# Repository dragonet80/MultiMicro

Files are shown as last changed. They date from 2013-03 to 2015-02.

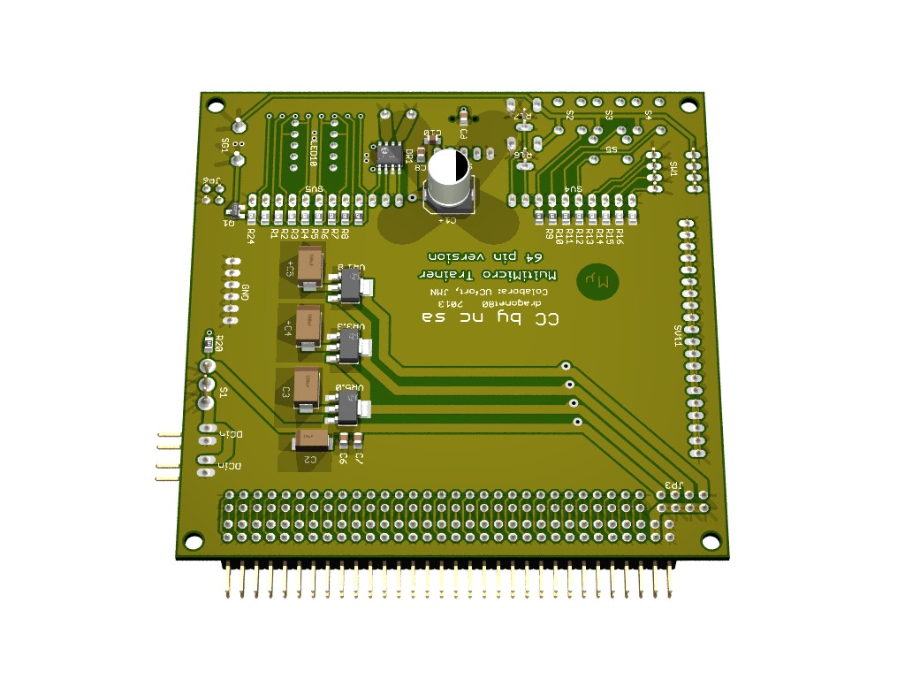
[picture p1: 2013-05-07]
Base/multiMicro_base_64pin_BOTTOM.jpg

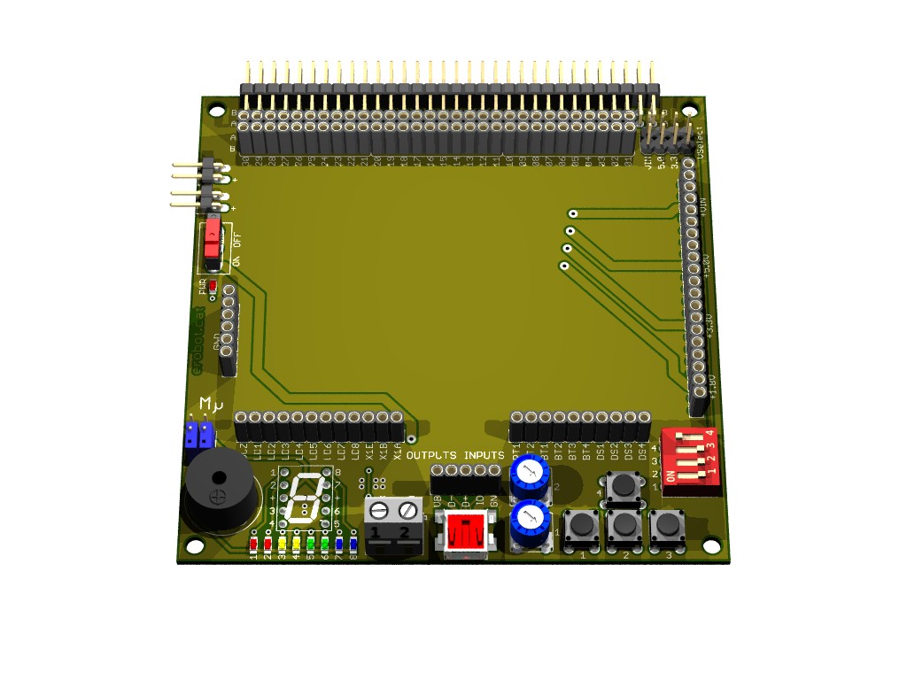
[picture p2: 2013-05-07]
Base/multiMicro_base_64pin_TOP.jpg

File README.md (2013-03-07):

MultiMicro
==========

MultiMicro Trainer is an small, simple and affordable microcontroller trainer everyone can use.
Its size is 10x10 cm, so you can order at a cheap price on online pcb manufarurers.

It's intended to be universal with any microcontroller from 6 to 100 pins and 5, 3.3 and 1.8 V.

It is formed by three parts:
* Base Trainer. It is the main pcb. It has voltage regulators, space for small breadboard, 8 push-buttons, 8 leds, 2 potenciometers and a buzzer. Plus, all connectors and pinheaders.
* Microcontroller adapter. You can make any adapter for your favorite microcontroller. You plug it to Base Trainer thru a 3x30 pinhead connector.
* Add-on boards. To add functionality. Preferred size is in multiples of 5x5 cm, to better fit Base Trainer, but can be any size.

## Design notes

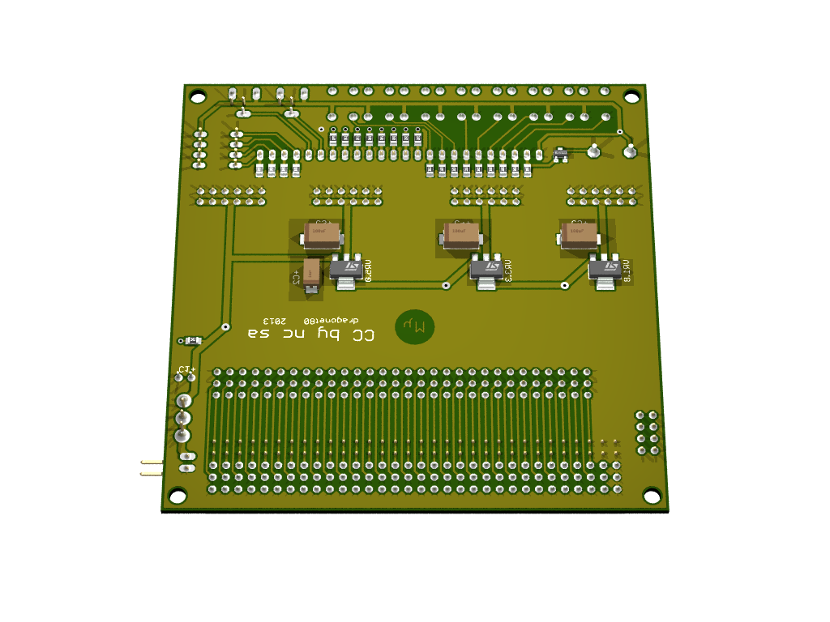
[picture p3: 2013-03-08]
Base/ARE_entrenadora_modular_doblecara_bis_BOT.bmp

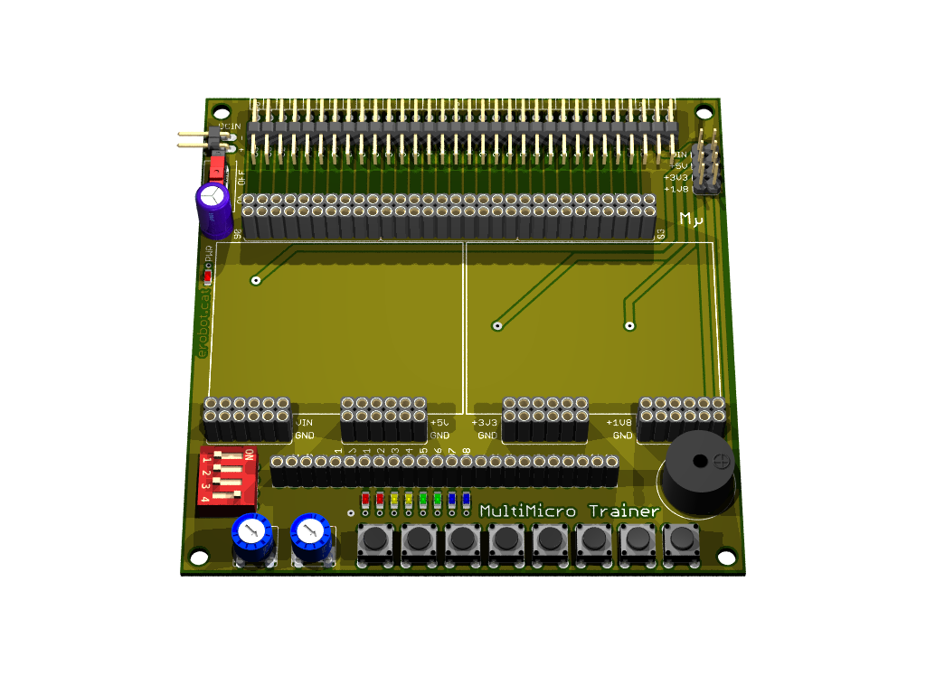
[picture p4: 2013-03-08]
Base/ARE_entrenadora_modular_doblecara_bis_TOP.bmp

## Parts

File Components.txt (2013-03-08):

* BASE:
-> 10uF Tantalo C: http://www.ebay.es/itm/10uF-TANTALUM-CAPACITOR-CASE-SIZE-C-10PCS-LOT-/251163093236#ht_500wt_1054
-> 100uF Tantalo E: http://www.ebay.es/itm/250974323237?ssPageName=STRK:MEWNX:IT&_trksid=p3984.m1439.l2649#ht_500wt_1054
-> 1.8V regulador: http://www.ebay.es/itm/200682889242?ssPageName=STRK:MEWNX:IT&_trksid=p3984.m1439.l2649
-> 3.3V regulador: http://www.ebay.es/itm/260700726343?ssPageName=STRK:MEWNX:IT&_trksid=p3984.m1439.l2649
-> 5.0V regulador: http://www.ebay.es/itm/130750914480?ssPageName=STRK:MEWNX:IT&_trksid=p3984.m1439.l2649
-> Leds de colors: http://www.ebay.es/itm/360537732340?ssPageName=STRK:MEWNX:IT&_trksid=p3984.m1439.l2649
-> 3x40 pinhead 90º: http://www.ebay.es/itm/180962786708?ssPageName=STRK:MEWNX:IT&_trksid=p3984.m1439.l2649
-> 3x40 pinhead femella: http://www.ebay.es/itm/170881419323?ssPageName=STRK:MEWNX:IT&_trksid=p3984.m1439.l2649
-> 2x40 pinhead femella: http://www.ebay.es/itm/170590329710?ssPageName=STRK:MEWNX:IT&_trksid=p3984.m1439.l2649
-> 1x40 pinhead femella: http://www.ebay.es/itm/170621688248?ssPageName=STRK:MEWNX:IT&_trksid=p3984.m1439.l2649
-> 2x40 pinhead: http://www.ebay.es/itm/170578500842?ssPageName=STRK:MEWAX:IT&_trksid=p3984.m1438.l2649
-> Mini breadboard + cables: http://www.ebay.es/itm/310513842038?ssPageName=STRK:MEWAX:IT&_trksid=p3984.m1438.l2649
-> Buzzer: http://www.ebay.es/itm/290576011848?ssPageName=STRK:MEWAX:IT&_trksid=p3984.m1438.l2649

* ADAPTADORES:
-> 1x40 pinhead femella 90º: http://www.ebay.es/itm/170876801011?ssPageName=STRK:MEWNX:IT&_trksid=p3984.m1439.l2649
-> 2x40 pinhead femella 90º: http://www.ebay.es/itm/160939073658?ssPageName=STRK:MEWNX:IT&_trksid=p3984.m1439.l2649
-> 2x20 pinhead femella 90º: http://www.ebay.es/itm/121021379218?ssPageName=STRK:MEWNX:IT&_trksid=p3984.m1439.l2649
-> 10uF Ceràmic 0805: http://www.ebay.es/itm/220983887703?ssPageName=STRK:MEWNX:IT&_trksid=p3984.m1439.l2649

* MÒDULS:

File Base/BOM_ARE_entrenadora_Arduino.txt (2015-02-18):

* ATMega32u4 tqfp:
http://www.ebay.es/itm/291281726764

* Breadboard + cables:
http://www.ebay.es/itm/310513842038

* Interruptor:
http://www.ebay.es/itm/310569872090

* Adaptador de voltatge:
http://es.farnell.com/texas-instruments/txs0104ed/ic-volt-level-translator-4bit/dp/1607892
http://www.ti.com/product/txs0104e/samplebuy
http://www.ebay.es/itm/TEXAS-INSTRUMENTS-TXS0104ED-IC-SM-LOGIC-TRANSLATOR-/351067941092

* Display 0,96" SPI:
http://www.ebay.es/itm/170842974902

* Potenciòmetres:
http://www.ebay.es/itm/321635537380

* Diodes:
http://www.ebay.es/itm/400647265186

* Ferrites:
http://www.ebay.es/itm/191479162526

* Mosfets tipus N:
http://www.ebay.es/itm/181291847700

* Mosfets tipus P:
http://www.ebay.es/itm/261261782429

* Condensadors 100uF 16V tipus C:
http://www.ebay.es/itm/291190614250

* 2x40 Male Pin Header 90º:
http://www.ebay.es/itm/140850530831

* Botons through hole:
http://www.ebay.es/itm/251146519833

* ESP8266 01:
http://www.ebay.es/itm/131334864936

* NRF24L01+:
http://www.ebay.es/itm/1pcs-NRF24L01-2-4GHz-Antenna-Wireless-Transceiver-Module-For-Microcontr-/171462149587

* HC-06:
http://www.ebay.es/itm/HC-06-RS232-Wireless-Serial-4-Pin-Bluetooth-RF-Transceiver-Module-With-backplane-/130984479388

* HM-10:
http://www.ebay.es/itm/HM-10-Transparent-Bluetooth-4-0-Serial-Port-Module-with-Logic-Level-Translator-/201260428325

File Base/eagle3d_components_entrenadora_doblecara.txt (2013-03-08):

INTERRUPTOR DIP(S1): SWITCH_SECME_1K2_SLB
BUZZER (SG1): SPC_BUZZER_TDB
PULSADOR (S2..S9): SWITCH_B3F_10XX1
POTENCIOMETRE (R22..R23): RES_DIS_TRIM_T7_YB

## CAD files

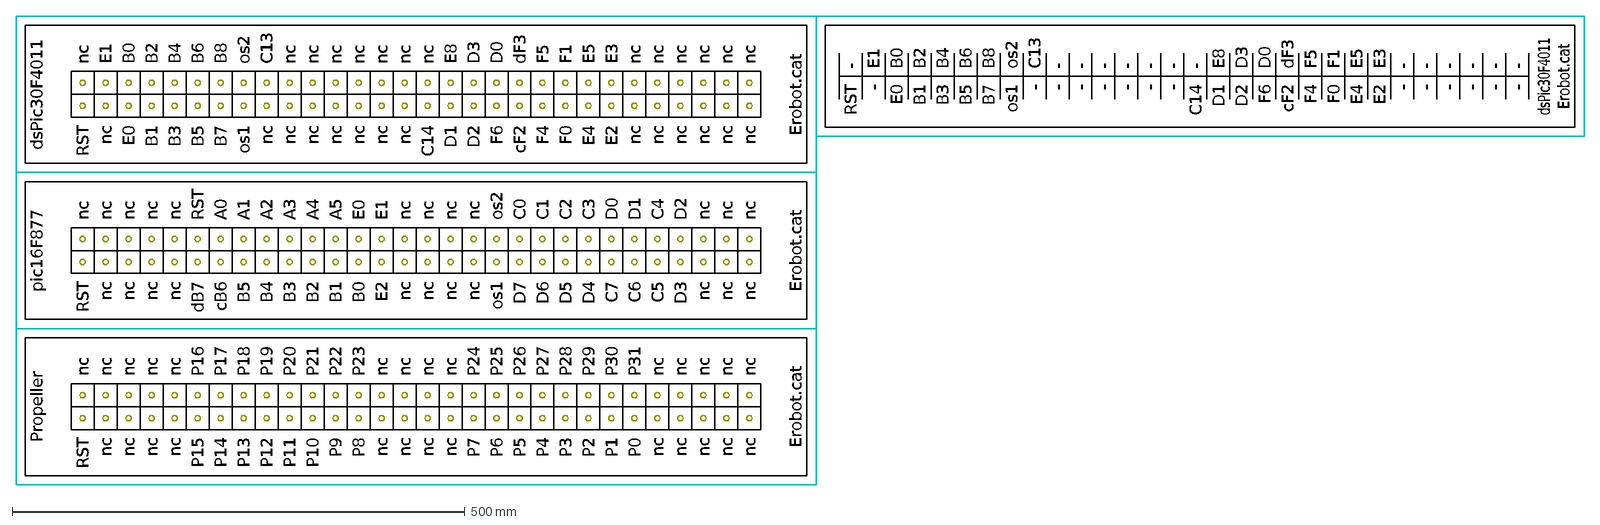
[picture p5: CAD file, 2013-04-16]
Plantilla_pins_entrenadora.dxf
RST
nc
E0
B1
B3
B5
B7
os1
C14
D1
D2
F6
cF2
F4
F0
E4
E2
E3
E5
F1
F5
dF3
D0
D3
E8
C13
os2
B8
B6
B4
B2
B0
E1
dsPic30F4011
Erobot.cat
dB7
cB6
D7
D6
D5
D4
C7
C6
C5
C4
C3
C2
C1
C0
A5
A4
A3
A2
A1
A0
pic16F877
P15
P14
P13
P12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

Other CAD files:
Plantilla_pins_entrenadora.dwg

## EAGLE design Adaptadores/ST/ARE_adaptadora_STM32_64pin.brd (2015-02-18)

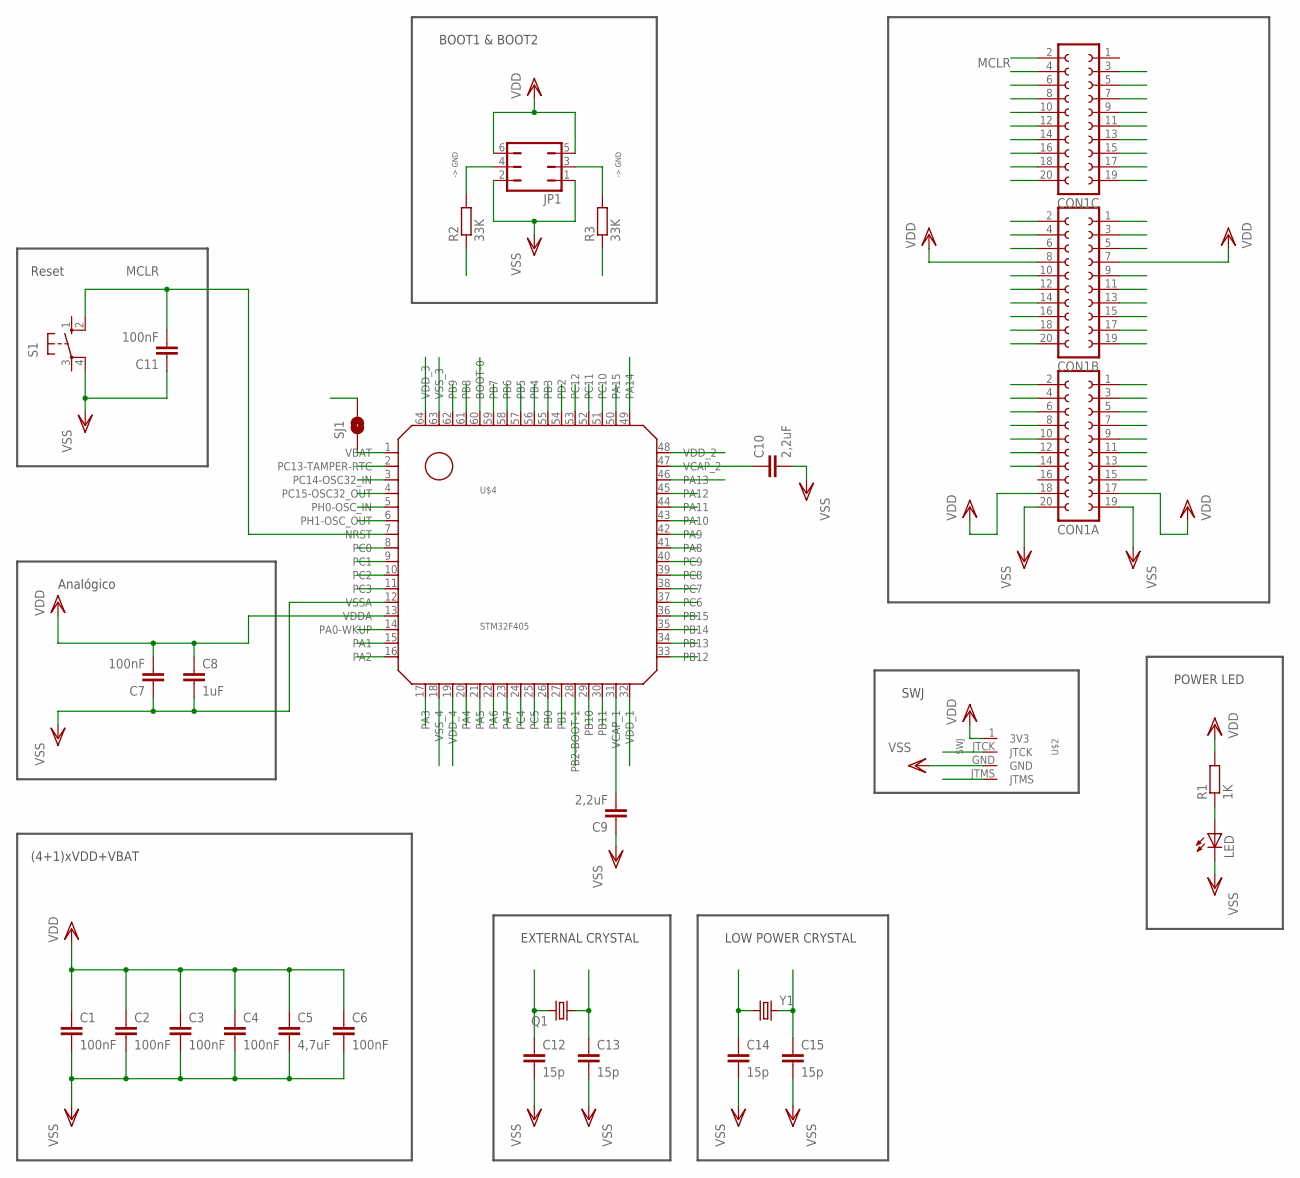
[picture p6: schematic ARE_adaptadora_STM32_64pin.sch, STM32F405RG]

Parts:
C1, C2, C3, C4, C6, C7, C11: 100nF; C0805K
C5: 4,7uF; C0805K
C8: 1uF; C0805K
C9, C10: 2,2uF; C0805K
C12, C13, C14, C15: 15p; C0805
CON1A, CON1B, CON1C: FE10-2W
JP1: JP3Q
LED: LEDCHIPLED_0805; CHIPLED_0805
Q1: CRYSTALHC18U-V; HC18U-V
R1: 1K; R0805
R2, R3: 33K; R0805
S1: 10-XX; B3F-10XX; MPN B3F-1000
SJ1: SOLDERJUMPERNO; SJ_2S-NO
U$2: SWJ
U$4: STM32F405; LQFP64
Y1: CRYSTAL32-SMD; CRYSTAL-32KHZ-SMD

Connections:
BOOT0: R2.1, U$4.60 (BOOT-0)
BOOT1: CON1B.3, R3.1, U$4.28 (PB2-BOOT-1)
JTCK: CON1A.3, U$2.JTCK, U$4.49 (PA14)
JTMS: CON1A.2, U$2.JTMS, U$4.46 (PA13)
MCLR: C11.2, CON1C.2, S1.2 (S1), U$4.7 (NRST)
unnamed: C10.1, U$4.47 (VCAP_2)
unnamed: C9.2, U$4.31 (VCAP_1)
unnamed: CON1C.4, U$4.2 (PC13-TAMPER-RTC)
unnamed: LED.A, R1.1
unnamed: CON1C.7, U$4.8 (PC0)
unnamed: CON1C.10, U$4.9 (PC1)
unnamed: CON1C.9, U$4.10 (PC2)
unnamed: CON1C.12, U$4.11 (PC3)
unnamed: CON1C.11, U$4.14 (PA0-WKUP)
unnamed: CON1C.14, U$4.15 (PA1)
unnamed: CON1C.13, U$4.16 (PA2)
unnamed: CON1C.16, U$4.17 (PA3)
unnamed: CON1C.15, U$4.20 (PA4)
unnamed: CON1C.18, U$4.21 (PA5)
unnamed: CON1C.17, U$4.22 (PA6)
unnamed: CON1C.20, U$4.23 (PA7)
unnamed: CON1C.19, U$4.24 (PC4)
unnamed: CON1B.2, U$4.25 (PC5)
unnamed: CON1B.1, U$4.26 (PB0)
unnamed: CON1B.4, U$4.27 (PB1)
unnamed: CON1B.6, U$4.29 (PB10)
unnamed: CON1B.5, U$4.30 (PB11)
unnamed: CON1B.9, U$4.33 (PB12)
unnamed: CON1B.10, U$4.34 (PB13)
unnamed: CON1B.11, U$4.35 (PB14)
unnamed: CON1B.12, U$4.36 (PB15)
unnamed: CON1B.13, U$4.37 (PC6)
unnamed: CON1B.14, U$4.38 (PC7)
unnamed: CON1B.15, U$4.39 (PC8)
unnamed: CON1B.16, U$4.40 (PC9)
unnamed: CON1B.17, U$4.41 (PA8)
unnamed: CON1B.18, U$4.42 (PA9)
unnamed: CON1B.19, U$4.43 (PA10)
unnamed: CON1B.20, U$4.44 (PA11)
unnamed: CON1A.1, U$4.45 (PA12)
unnamed: CON1A.4, U$4.50 (PA15)
unnamed: CON1A.5, U$4.51 (PC10)
unnamed: CON1A.6, U$4.52 (PC11)
unnamed: CON1A.7, U$4.53 (PC12)
unnamed: CON1A.8, U$4.54 (PD2)
unnamed: CON1A.9, U$4.55 (PB3)
unnamed: CON1A.10, U$4.56 (PB4)
unnamed: CON1A.11, U$4.57 (PB5)
unnamed: CON1A.12, U$4.58 (PB6)
unnamed: CON1A.13, U$4.59 (PB7)
unnamed: CON1A.14, U$4.61 (PB8)
unnamed: CON1A.15, U$4.62 (PB9)
unnamed: JP1.4, R2.2
unnamed: JP1.3, R3.2
P12OSC0: C13.1, CON1C.5, Q1.1, U$4.5 (PH0-OSC_IN)
P12OSC1: C12.1, CON1C.8, Q1.2, U$4.6 (PH1-OSC_OUT)
P12OSC320: C14.1, CON1C.3, U$4.3 (PC14-OSC32_IN), Y1.X1 (1)
P12OSC321: C15.1, CON1C.6, U$4.4 (PC15-OSC32_OUT), Y1.X2 (2)
VBAT: SJ1.1, U$4.1 (VBAT)
VDD: C1.1, C2.1, C3.1, C4.1, C5.1, C6.1, C7.2, C8.1, CON1A.17, CON1A.18, CON1B.7, CON1B.8, JP1.5, JP1.6, R1.2, SJ1.2, U$2.1 (3V3), U$4.13 (VDDA), U$4.19 (VDD_4), U$4.32 (VDD_1), U$4.48 (VDD_2), U$4.64 (VDD_3)
VSS: C1.2, C2.2, C3.2, C4.2, C5.2, C6.2, C7.1, C8.2, C9.1, C10.2, C11.1, C12.2, C13.2, C14.2, C15.2, CON1A.19, CON1A.20, JP1.1, JP1.2, LED.C, S1.4 (P1), U$2.GND, U$4.12 (VSSA), U$4.18 (VSS_4), U$4.63 (VSS_3)

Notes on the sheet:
(4+1)xVDD+VBAT
Reset
-> GND
BOOT1 & BOOT2
SWJ
Analógico
EXTERNAL CRYSTAL
POWER LED
LOW POWER CRYSTAL

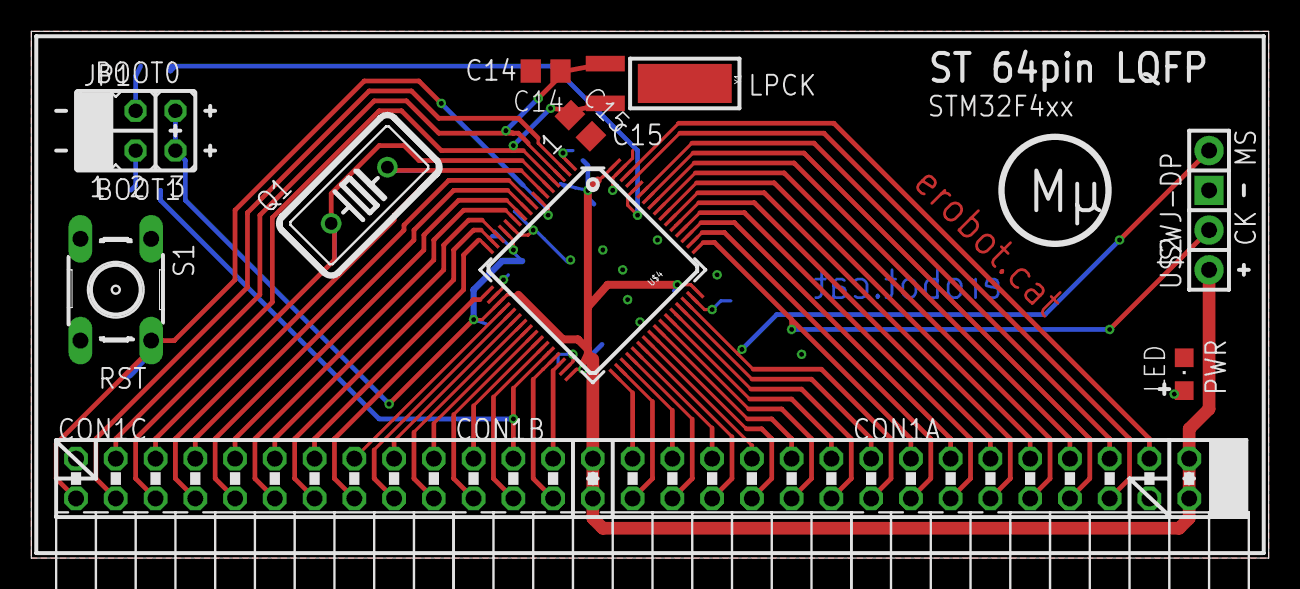
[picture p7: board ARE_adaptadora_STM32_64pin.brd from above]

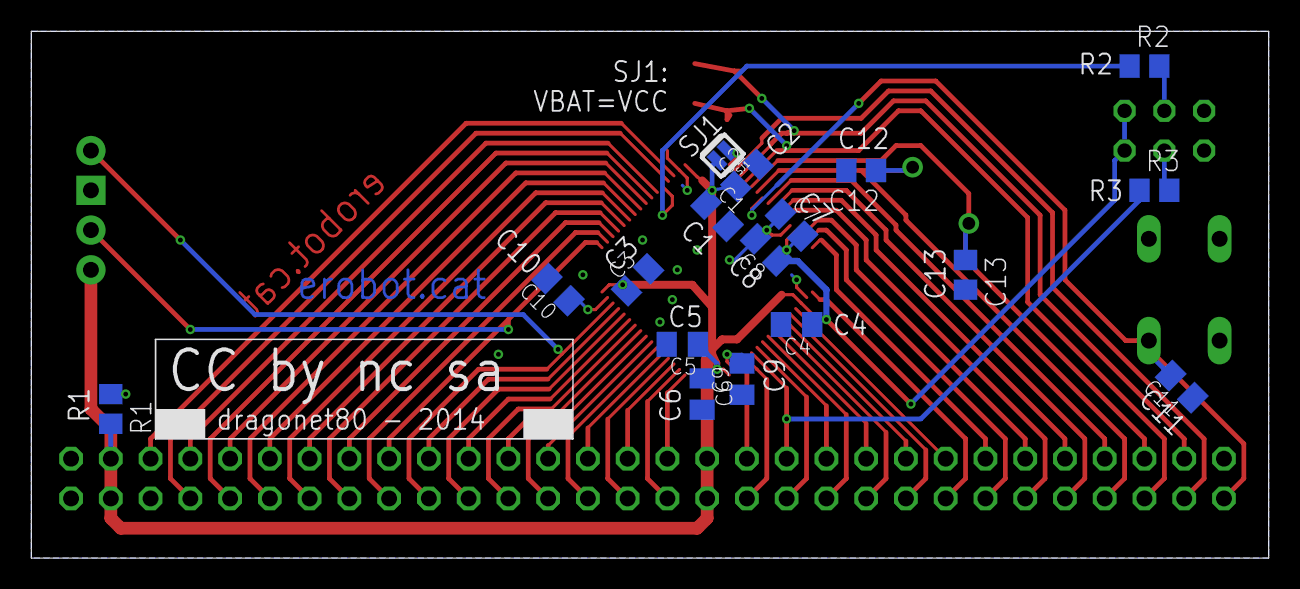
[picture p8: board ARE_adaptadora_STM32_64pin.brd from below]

Board: 2 copper layers, 79.1 x 33.7 mm, 29 parts (17 on the bottom side), 61 nets.

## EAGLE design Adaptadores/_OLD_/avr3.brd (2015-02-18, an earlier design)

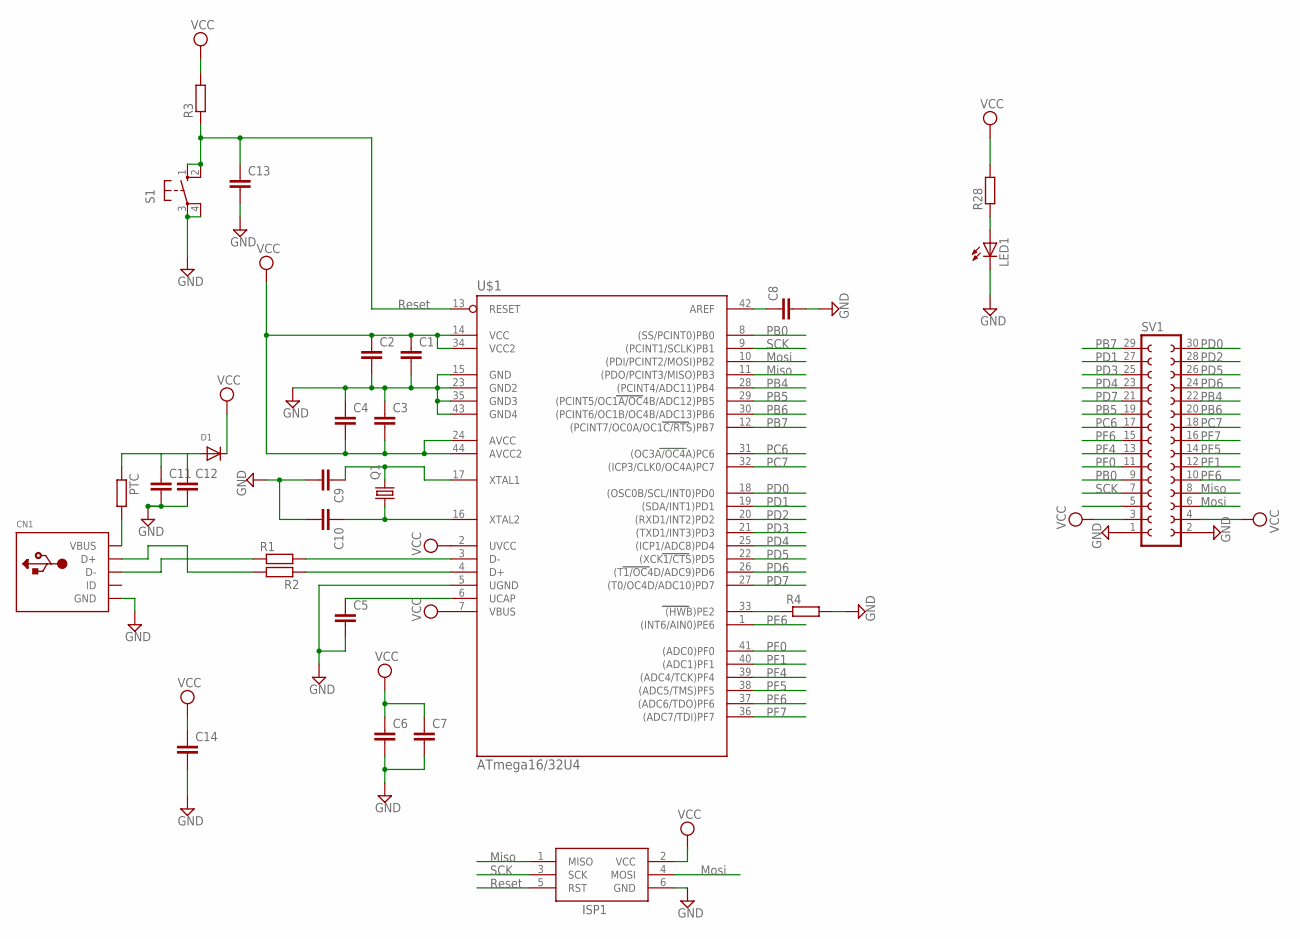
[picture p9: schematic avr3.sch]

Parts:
C1, C2, C3, C4, C5, C6, C7, C8, C9, C10, C11, C12, C13, C14: C-EUC1206; C1206
CN1: USBMINIB; USB-MINIB
D1: DIODESOD-123; SOD-123
ISP1: AVRISP-6; AVRISP
LED1: LEDCHIPLED_1206; CHIPLED_1206
PTC: R-EU_R1206; R1206
Q1: CRYSTALHC49UP; HC49UP
R1, R2, R3, R4, R28: R-EU_R1206; R1206
S1: 10-XX; B3F-10XX
SV1: FE15-2
U$1: ATmega16/32U4; TQFP44

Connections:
GND: C1.2, C2.2, C3.1, C4.1, C5.2, C6.2, C7.2, C8.2, C9.2, C10.2, C11.2, C12.2, C13.2, C14.2, CN1.GND, ISP1.6 (GND), LED1.C, R4.2, S1.3, S1.4 (P1), SV1.1, SV1.2, U$1.5 (UGND), U$1.15 (GND), U$1.23 (GND2), U$1.35 (GND3), U$1.43 (GND4)
MISO: ISP1.1 (MISO), SV1.8, U$1.11 ((PDO/PCINT3/MISO)PB3)
MOSI: ISP1.4 (MOSI), SV1.6, U$1.10 ((PDI/PCINT2/MOSI)PB2)
unnamed: C9.1, Q1.2, U$1.17 (XTAL1)
unnamed: C10.1, Q1.1, U$1.16 (XTAL2)
unnamed: C5.1, U$1.6 (UCAP)
unnamed: R4.1, U$1.33 ((HWB)PE2)
unnamed: R2.1, U$1.4 (D+)
unnamed: R1.2, U$1.3 (D-)
unnamed: CN1.D+, R2.2
unnamed: CN1.D-, R1.1
unnamed: CN1.VBUS, PTC.2
unnamed: C11.1, C12.1, D1.A, PTC.1
unnamed: C8.1, U$1.42 (AREF)
unnamed: LED1.A, R28.1
PB0: SV1.9, U$1.8 ((SS/PCINT0)PB0)
PB4: SV1.22, U$1.28 ((PCINT4/ADC11)PB4)
PB5: SV1.19, U$1.29 ((PCINT5/OC1A/OC4B/ADC12)PB5)
PB6: SV1.20, U$1.30 ((PCINT6/OC1B/OC4B/ADC13)PB6)
PB7: SV1.29, U$1.12 ((PCINT7/OC0A/OC1C/RTS)PB7)
PC6: SV1.17, U$1.31 ((OC3A/OC4A)PC6)
PC7: SV1.18, U$1.32 ((ICP3/CLK0/OC4A)PC7)
PD0: SV1.30, U$1.18 ((OSC0B/SCL/INT0)PD0)
PD1: SV1.27, U$1.19 ((SDA/INT1)PD1)
PD2: SV1.28, U$1.20 ((RXD1/INT2)PD2)
PD3: SV1.25, U$1.21 ((TXD1/INT3)PD3)
PD4: SV1.23, U$1.25 ((ICP1/ADC8)PD4)
PD5: SV1.26, U$1.22 ((XCK1/CTS)PD5)
PD6: SV1.24, U$1.26 ((T1/OC4D/ADC9)PD6)
PD7: SV1.21, U$1.27 ((T0/OC4D/ADC10)PD7)
PE6: SV1.10, U$1.1 ((INT6/AIN0)PE6)
PF0: SV1.11, U$1.41 ((ADC0)PF0)
PF1: SV1.12, U$1.40 ((ADC1)PF1)
PF4: SV1.13, U$1.39 ((ADC4/TCK)PF4)
PF5: SV1.14, U$1.38 ((ADC5/TMS)PF5)
PF6: SV1.15, U$1.37 ((ADC6/TDO)PF6)
PF7: SV1.16, U$1.36 ((ADC7/TDI)PF7)
RESET: C13.1, ISP1.5 (RST), R3.1, S1.1 (S), S1.2 (S1), U$1.13 (RESET)
SCK: ISP1.3 (SCK), SV1.7, U$1.9 ((PCINT1/SCLK)PB1)
VCC: C1.1, C2.1, C3.2, C4.2, C6.1, C7.1, C14.1, D1.C, ISP1.2 (VCC), R3.2, R28.2, SV1.3, SV1.4, U$1.2 (UVCC), U$1.7 (VBUS), U$1.14 (VCC), U$1.24 (AVCC), U$1.34 (VCC2), U$1.44 (AVCC2)

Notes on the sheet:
Reset
Miso
Mosi
SCK
PB7
PB6
PB5
PB4
PB0
PC6
PC7
PD0
PD1
PD2
PD3
PD4
PD5
PD6
PD7
PE6
PF0
PF1
PF4
PF5
PF6
PF7

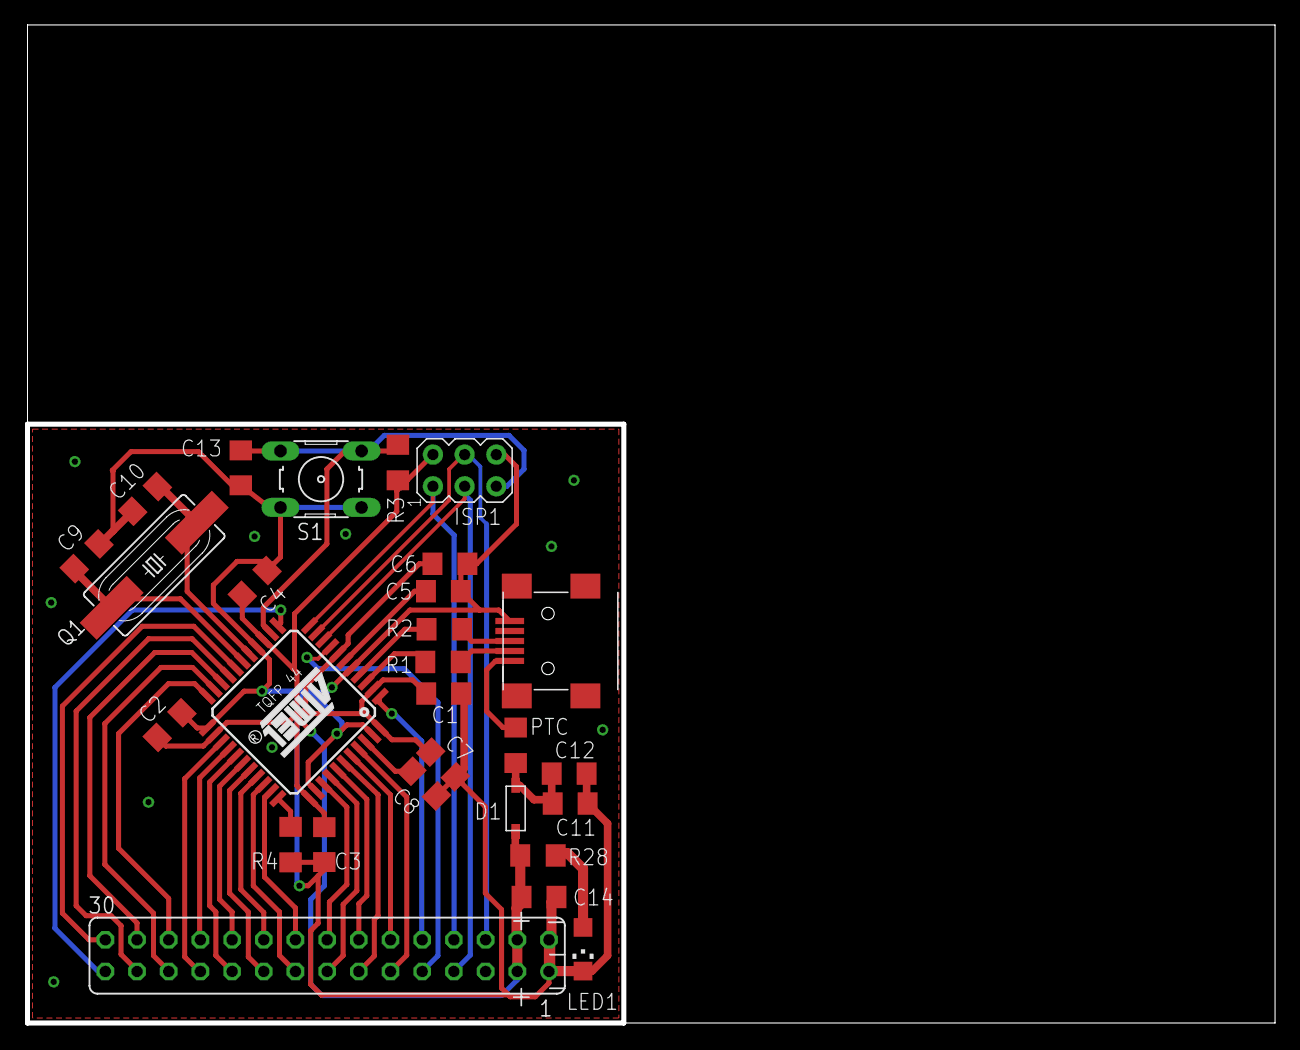
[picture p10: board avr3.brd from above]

Board: 2 copper layers, 100.0 x 80.0 mm, 28 parts (0 on the bottom side), 40 nets.

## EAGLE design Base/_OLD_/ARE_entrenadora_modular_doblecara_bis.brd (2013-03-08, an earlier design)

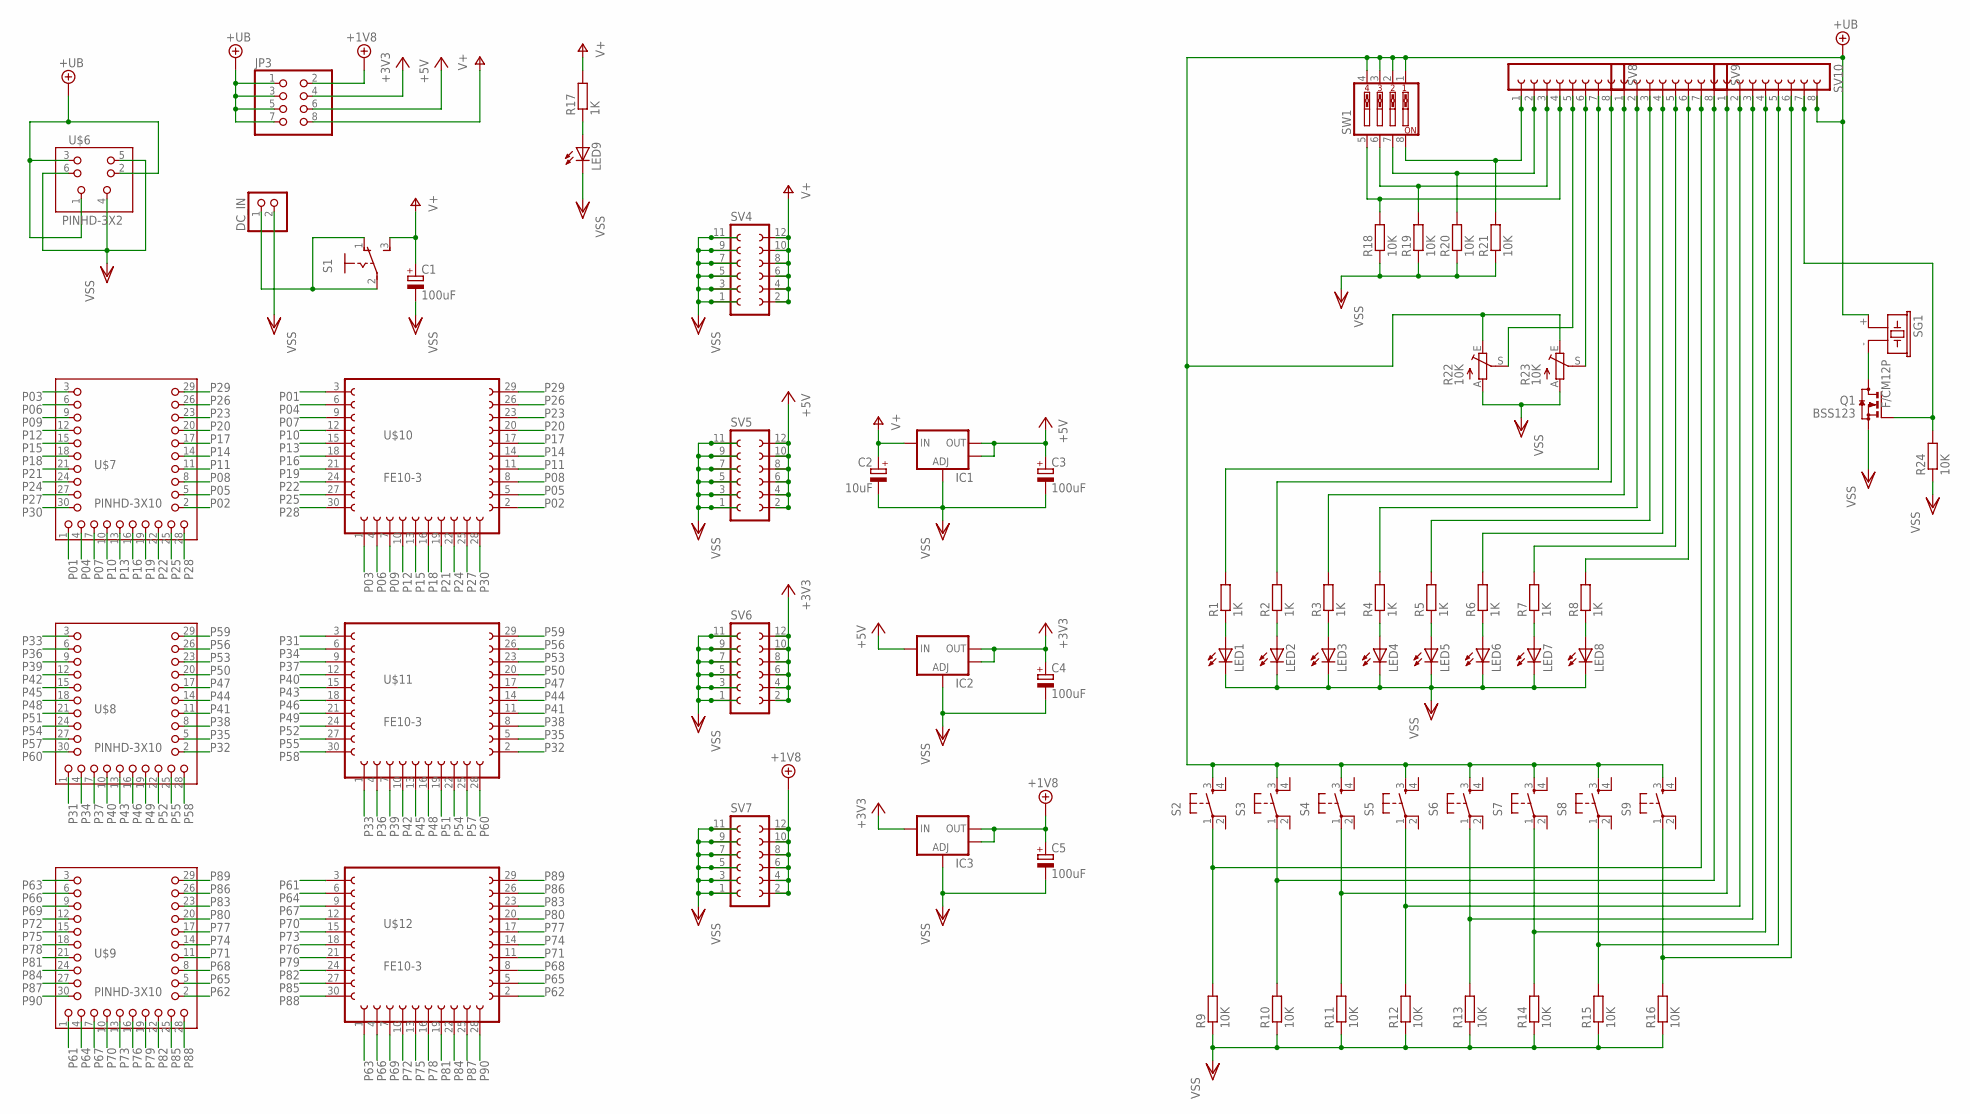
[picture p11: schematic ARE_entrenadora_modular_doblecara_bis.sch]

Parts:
C1: 100uF; E2,5-6
C2: 10uF; SMC_C
C3, C4, C5: 100uF; CT7343
DC_IN: PINHD-1X2/90; 1X02/90
IC1, IC2, IC3: V_REG_LM1117SOT223; SOT223
JP3: PINHD-2X4; 2X04
LED1, LED2, LED3, LED4, LED5, LED6, LED7, LED8, LED9: LEDCHIP-LED0805; CHIP-LED0805
Q1: BSS123; SOT23
R1, R2, R3, R4, R5, R6, R7, R8, R17: 1K; R0805
R9, R10, R11, R12, R13, R14, R15, R16, R18, R19, R20, R21, R24: 10K; R0805
R22, R23: 10K; CA6V
S1: 255SB
S2, S3, S4, S5, S6, S7, S8, S9: TAC_SWITCHPTH; TACTILE-PTH
SG1: F/CM12P
SV4, SV5, SV6, SV7: FE06-2
SV8, SV9, SV10: FE08-1; FE08
SW1: SW_DIP-4; EDG-04
U$6: PINHD-3X2; 3X02/90
U$7, U$8, U$9: PINHD-3X10; 3X10/90
U$10, U$11, U$12: FE10-3

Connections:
+3V3: C4.+, IC2.2 (OUT), IC2.4 (OUT), IC3.3 (IN), JP3.4, SV6.2, SV6.4, SV6.6, SV6.8, SV6.10, SV6.12
+5V: C3.+, IC1.2 (OUT), IC1.4 (OUT), IC2.3 (IN), JP3.6, SV5.2, SV5.4, SV5.6, SV5.8, SV5.10, SV5.12
+18V: C5.+, IC3.2 (OUT), IC3.4 (OUT), JP3.2, SV7.2, SV7.4, SV7.6, SV7.8, SV7.10, SV7.12
+UB: JP3.1, JP3.3, JP3.5, JP3.7, R22.E, R23.E, S2.3, S3.3, S4.3, S5.3, S6.3, S7.3, S8.3, S9.3, SG1.+ (1), SV10.8, SW1.1, SW1.2, SW1.3, SW1.4, U$6.1, U$6.2, U$6.3
unnamed: LED1.A, R1.1
unnamed: LED2.A, R2.1
unnamed: LED3.A, R3.1
unnamed: LED4.A, R4.1
unnamed: R2.2, SV8.8
unnamed: R3.2, SV9.1
unnamed: R1.2, SV8.7
unnamed: R4.2, SV9.2
unnamed: LED9.A, R17.1
unnamed: Q1.3 (D), SG1.- (2)
unnamed: DC_IN.1, S1.1 (O), S1.2
unnamed: LED5.A, R5.1
unnamed: LED6.A, R6.1
unnamed: LED7.A, R7.1
unnamed: LED8.A, R8.1
unnamed: R9.2, S2.1, SV9.7
unnamed: R10.2, S3.1, SV9.8
unnamed: R11.2, S4.1, SV10.1
unnamed: R12.2, S5.1, SV10.2
unnamed: R13.2, S6.1, SV10.3
unnamed: R14.2, S7.1, SV10.4
unnamed: R15.2, S8.1, SV10.5
unnamed: R16.2, S9.1, SV10.6
unnamed: Q1.1 (G), R24.2, SV10.7
unnamed: R23.S, SV8.6
unnamed: R22.S, SV8.5
unnamed: R6.2, SV9.4
unnamed: R7.2, SV9.5
unnamed: R5.2, SV9.3
unnamed: R8.2, SV9.6
unnamed: R18.2, SV8.4, SW1.5
unnamed: R19.2, SV8.3, SW1.6
unnamed: R20.2, SV8.2, SW1.7
unnamed: R21.2, SV8.1, SW1.8
P01: U$7.1, U$10.3
P02: U$7.2, U$10.2
P03: U$7.3, U$10.1
P04: U$7.4, U$10.6
P05: U$7.5, U$10.5
P06: U$7.6, U$10.4
P07: U$7.7, U$10.9
P08: U$7.8, U$10.8
P09: U$7.9, U$10.7
P10: U$7.10, U$10.12
P11: U$7.11, U$10.11
P12: U$7.12, U$10.10
P13: U$7.13, U$10.15
P14: U$7.14, U$10.14
P15: U$7.15, U$10.13
P16: U$7.16, U$10.18
P17: U$7.17, U$10.17
P18: U$7.18, U$10.16
P19: U$7.19, U$10.21
P20: U$7.20, U$10.20
P21: U$7.21, U$10.19
P22: U$7.22, U$10.24
P23: U$7.23, U$10.23
P24: U$7.24, U$10.22
P25: U$7.25, U$10.27
P26: U$7.26, U$10.26
P27: U$7.27, U$10.25
P28: U$7.28, U$10.30
P29: U$7.29, U$10.29
P30: U$7.30, U$10.28
P31: U$8.1, U$11.3
P32: U$8.2, U$11.2
P33: U$8.3, U$11.1
P34: U$8.4, U$11.6
P35: U$8.5, U$11.5
P36: U$8.6, U$11.4
P37: U$8.7, U$11.9
P38: U$8.8, U$11.8
P39: U$8.9, U$11.7
P40: U$8.10, U$11.12
P41: U$8.11, U$11.11
P42: U$8.12, U$11.10
P43: U$8.13, U$11.15
P44: U$8.14, U$11.14
P45: U$8.15, U$11.13
P46: U$8.16, U$11.18
P47: U$8.17, U$11.17
P48: U$8.18, U$11.16
P49: U$8.19, U$11.21
P50: U$8.20, U$11.20
P51: U$8.21, U$11.19
P52: U$8.22, U$11.24
P53: U$8.23, U$11.23
P54: U$8.24, U$11.22
P55: U$8.25, U$11.27
P56: U$8.26, U$11.26
P57: U$8.27, U$11.25
P58: U$8.28, U$11.30
P59: U$8.29, U$11.29
P60: U$8.30, U$11.28
P61: U$9.1, U$12.3
P62: U$9.2, U$12.2
P63: U$9.3, U$12.1
P64: U$9.4, U$12.6
P65: U$9.5, U$12.5
P66: U$9.6, U$12.4
P67: U$9.7, U$12.9
P68: U$9.8, U$12.8
P69: U$9.9, U$12.7
P70: U$9.10, U$12.12
P71: U$9.11, U$12.11
P72: U$9.12, U$12.10
P73: U$9.13, U$12.15
P74: U$9.14, U$12.14
P75: U$9.15, U$12.13
P76: U$9.16, U$12.18
P77: U$9.17, U$12.17
P78: U$9.18, U$12.16
P79: U$9.19, U$12.21
P80: U$9.20, U$12.20
P81: U$9.21, U$12.19
P82: U$9.22, U$12.24
P83: U$9.23, U$12.23
P84: U$9.24, U$12.22
P85: U$9.25, U$12.27
P86: U$9.26, U$12.26
P87: U$9.27, U$12.25
P88: U$9.28, U$12.30
P89: U$9.29, U$12.29
P90: U$9.30, U$12.28
V+: C1.+, C2.+, IC1.3 (IN), JP3.8, R17.2, S1.3 (S), SV4.2, SV4.4, SV4.6, SV4.8, SV4.10, SV4.12
VSS: C1.-, C2.-, C3.-, C4.-, C5.-, DC_IN.2, IC1.1 (ADJ), IC2.1 (ADJ), IC3.1 (ADJ), LED1.C, LED2.C, LED3.C, LED4.C, LED5.C, LED6.C, LED7.C, LED8.C, LED9.C, Q1.2 (S), R9.1, R10.1, R11.1, R12.1, R13.1, R14.1, R15.1, R16.1, R18.1, R19.1, R20.1, R21.1, R22.A, R23.A, R24.1, SV4.1, SV4.3, SV4.5, SV4.7, SV4.9, SV4.11, SV5.1, SV5.3, SV5.5, SV5.7, SV5.9, SV5.11, SV6.1, SV6.3, SV6.5, SV6.7, SV6.9, SV6.11, SV7.1, SV7.3, SV7.5, SV7.7, SV7.9, SV7.11, U$6.4, U$6.5, U$6.6

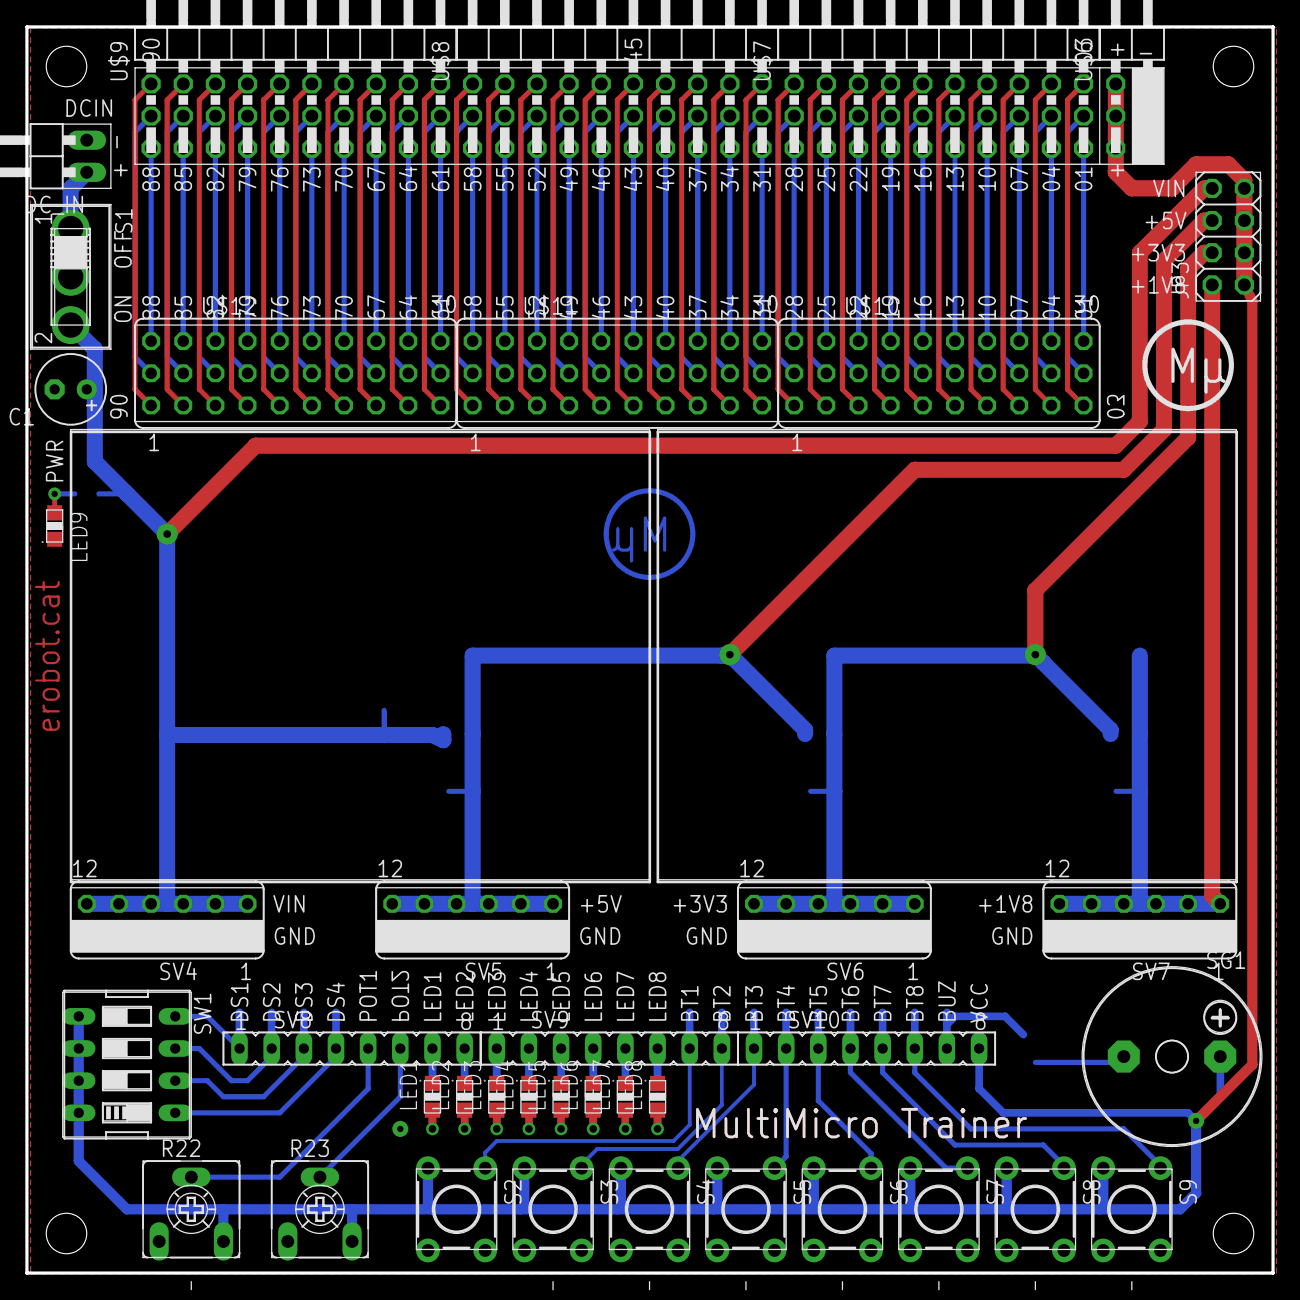
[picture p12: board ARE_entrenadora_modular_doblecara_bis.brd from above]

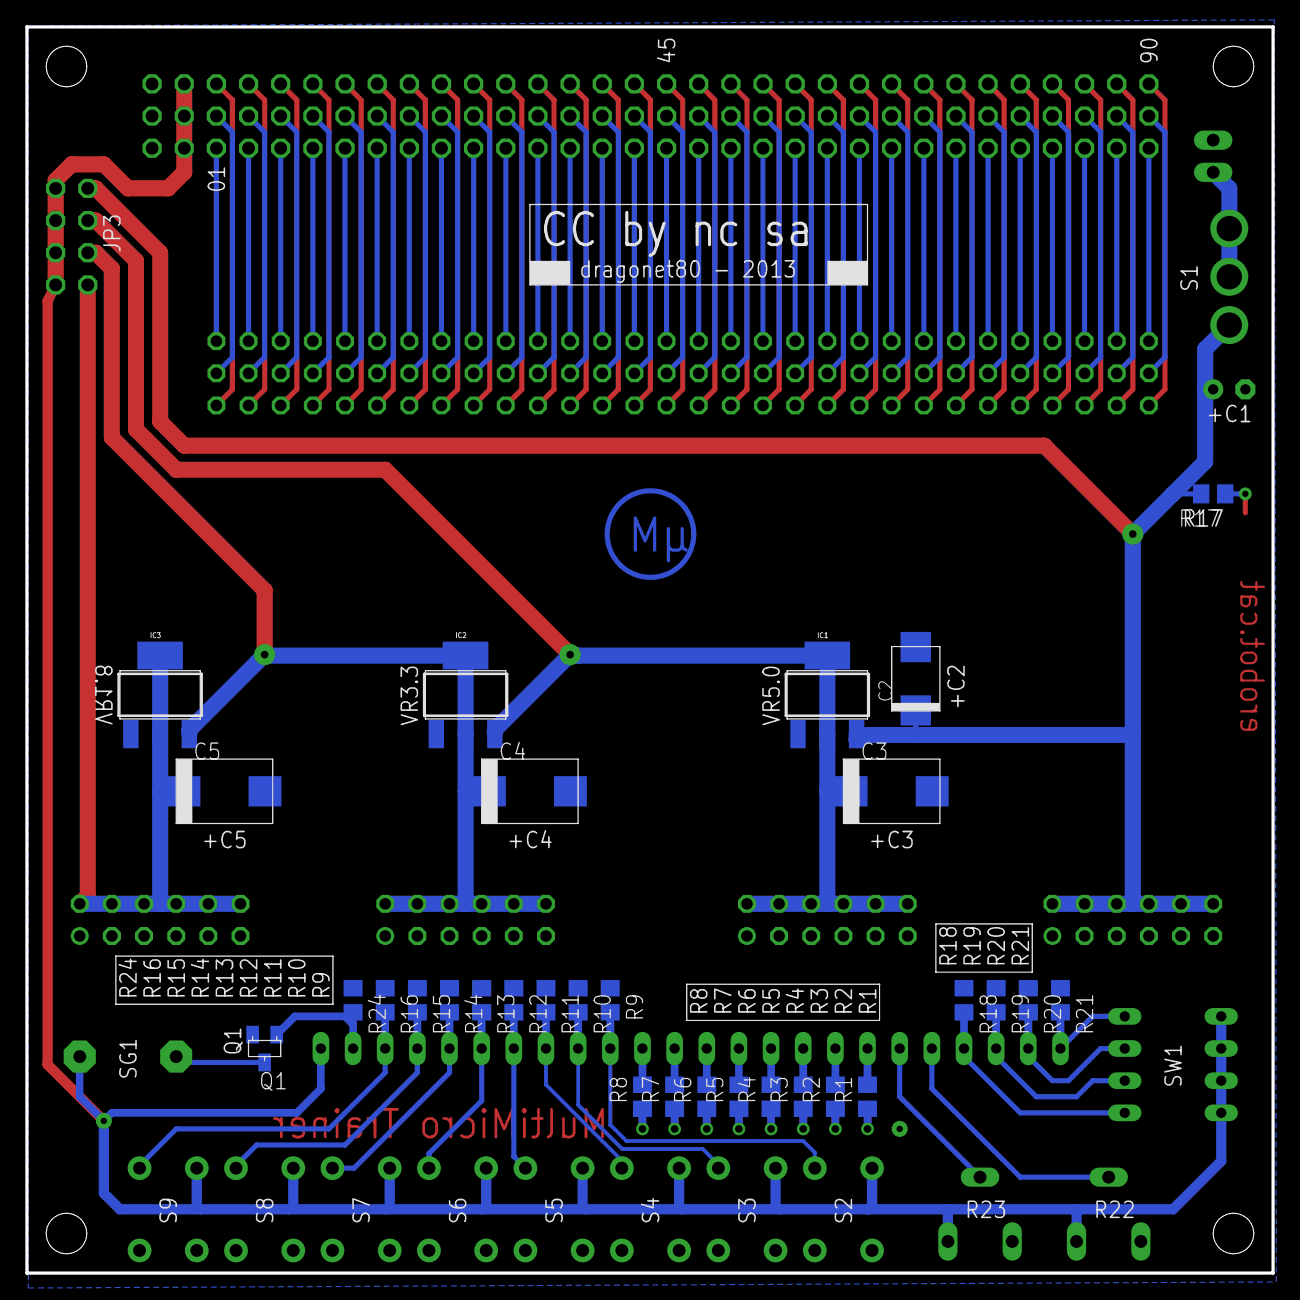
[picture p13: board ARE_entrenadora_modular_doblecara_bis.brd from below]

Board: 2 copper layers, 98.4 x 98.4 mm, 71 parts (30 on the bottom side), 130 nets.

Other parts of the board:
U$2, U$3: BREADBOARDMINI; BREADBOARD-MINI

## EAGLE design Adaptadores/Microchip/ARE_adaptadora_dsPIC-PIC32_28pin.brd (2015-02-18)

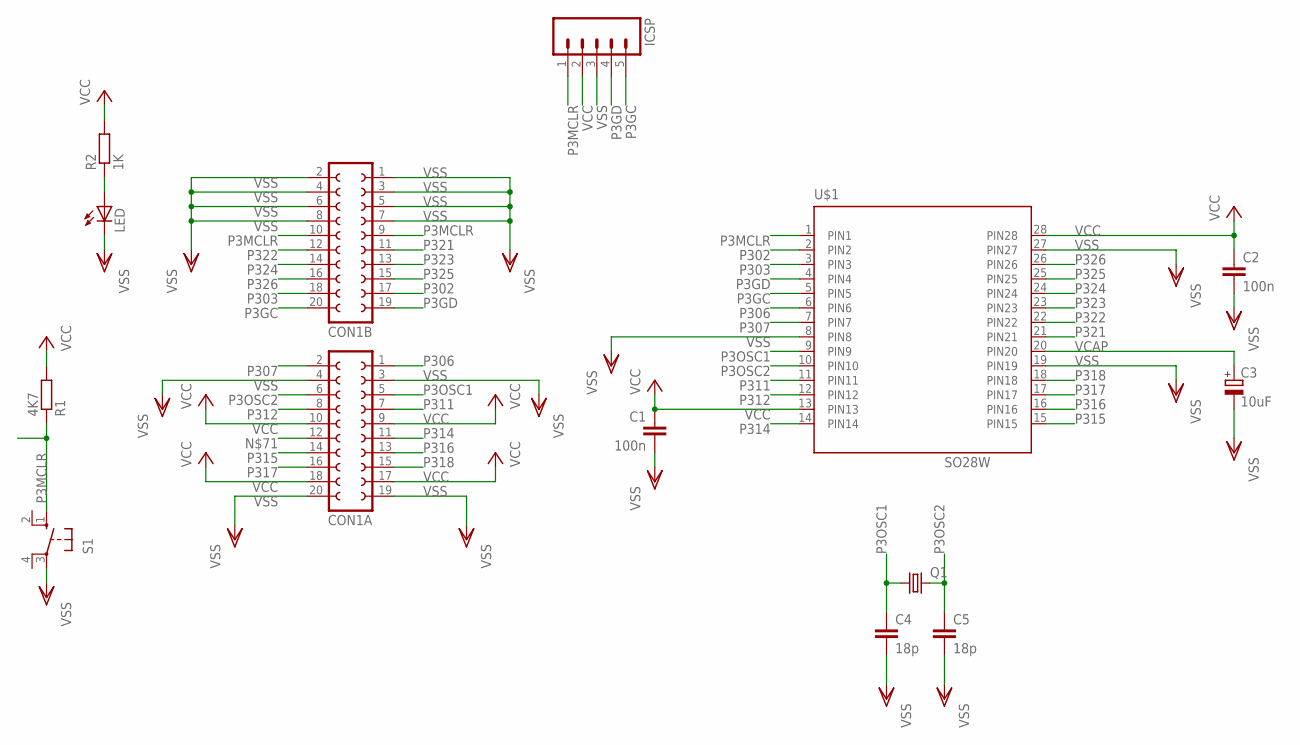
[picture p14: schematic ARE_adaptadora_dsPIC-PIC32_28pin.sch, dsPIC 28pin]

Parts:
C1, C2: 100n; C0805
C3: 10uF; SMC_C
C4, C5: 18p; C0805
CON1A, CON1B: FE10-2W
ICSP: M05PTH; 1X05
LED: LEDCHIPLED_0805; CHIPLED_0805
Q1: CRYSTALHC18U-V; HC18U-V
R1: 4K7; R0805
R2: 1K; R0805
S1: 10-XX; B3F-10XX; MPN B3F-1000
U$1: SO28W

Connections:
unnamed: LED.A, R2.1
P3GC: CON1B.20, ICSP.5, U$1.5 (PIN5)
P3GD: CON1B.19, ICSP.4, U$1.4 (PIN4)
P3MCLR: CON1B.9, CON1B.10, ICSP.1, R1.1, S1.1 (S), U$1.1 (PIN1)
P3OSC1: C4.1, CON1A.5, Q1.1, U$1.9 (PIN9)
P3OSC2: C5.1, CON1A.6, Q1.2, U$1.10 (PIN10)
P302: CON1B.17, U$1.2 (PIN2)
P303: CON1B.18, U$1.3 (PIN3)
P306: CON1A.1, U$1.6 (PIN6)
P307: CON1A.2, U$1.7 (PIN7)
P311: CON1A.7, U$1.11 (PIN11)
P312: CON1A.8, U$1.12 (PIN12)
P314: CON1A.11, U$1.14 (PIN14)
P315: CON1A.14, U$1.15 (PIN15)
P316: CON1A.13, U$1.16 (PIN16)
P317: CON1A.16, U$1.17 (PIN17)
P318: CON1A.15, U$1.18 (PIN18)
P321: CON1B.11, U$1.21 (PIN21)
P322: CON1B.12, U$1.22 (PIN22)
P323: CON1B.13, U$1.23 (PIN23)
P324: CON1B.14, U$1.24 (PIN24)
P325: CON1B.15, U$1.25 (PIN25)
P326: CON1B.16, U$1.26 (PIN26)
VCAP: C3.+, U$1.20 (PIN20)
VCC: C1.1, C2.1, CON1A.9, CON1A.10, CON1A.17, CON1A.18, ICSP.2, R1.2, R2.2, U$1.13 (PIN13), U$1.28 (PIN28)
VSS: C1.2, C2.2, C3.-, C4.2, C5.2, CON1A.3, CON1A.4, CON1A.19, CON1A.20, CON1B.1, CON1B.2, CON1B.3, CON1B.4, CON1B.5, CON1B.6, CON1B.7, CON1B.8, ICSP.3, LED.C, S1.3, U$1.8 (PIN8), U$1.19 (PIN19), U$1.27 (PIN27)

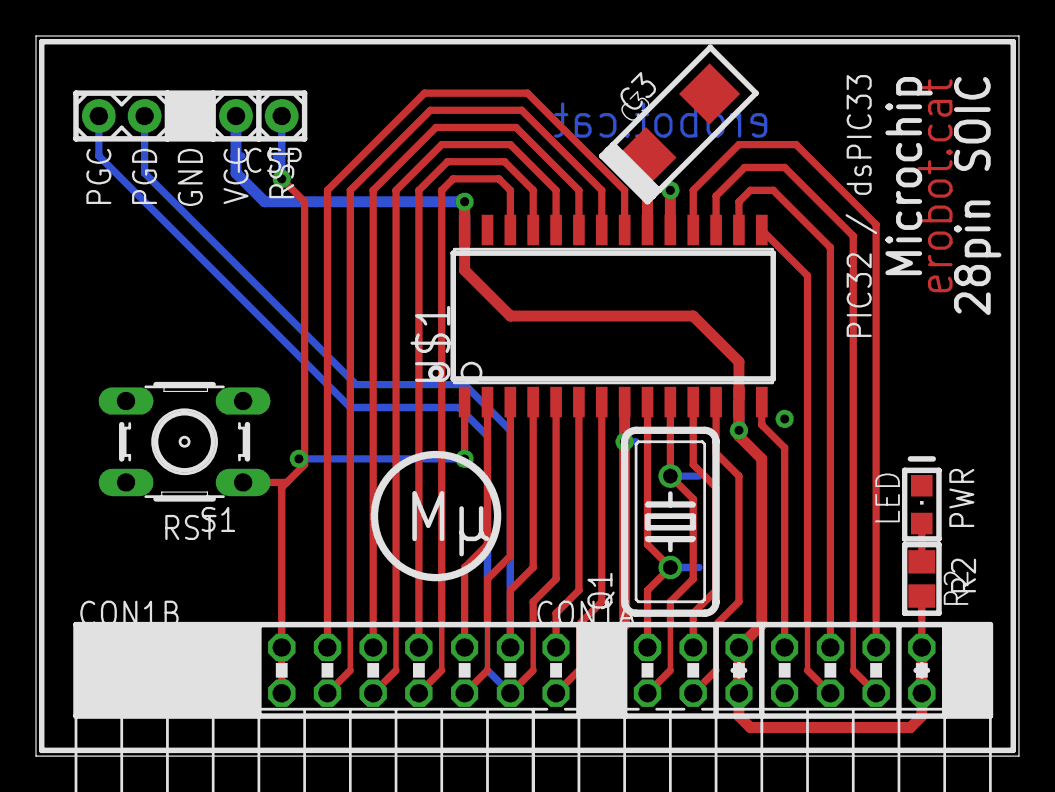
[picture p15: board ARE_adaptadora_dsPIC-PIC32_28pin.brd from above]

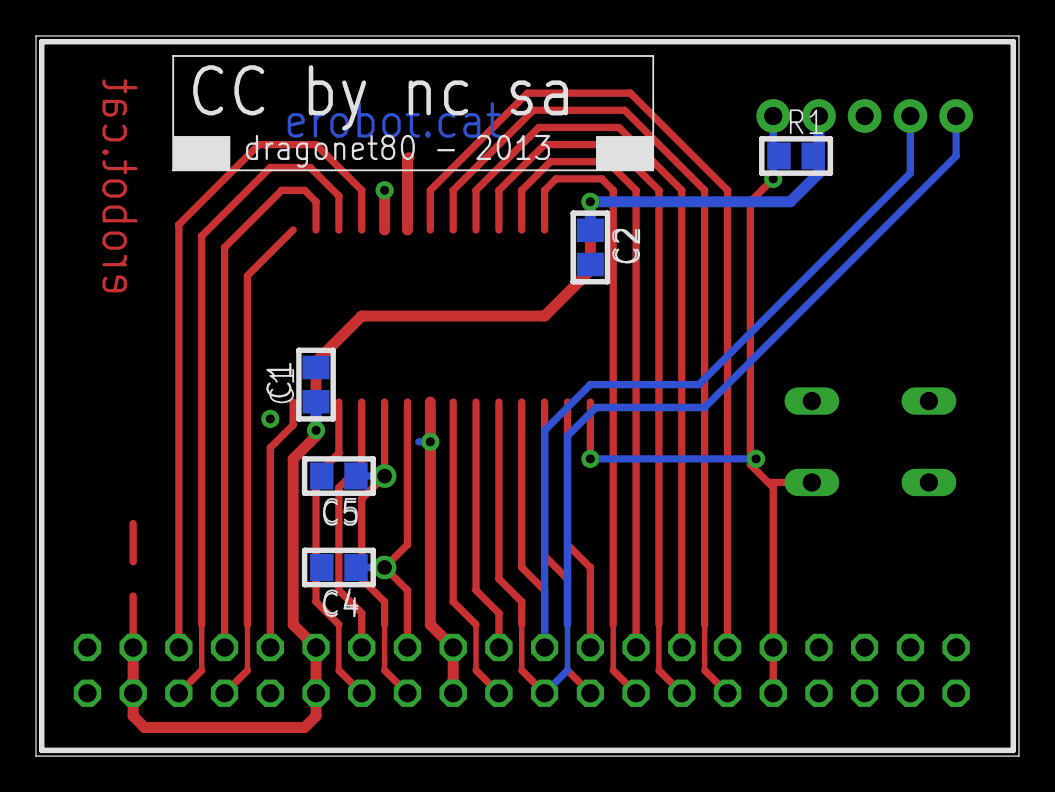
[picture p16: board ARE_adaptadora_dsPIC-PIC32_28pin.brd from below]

Board: 2 copper layers, 54.6 x 40.0 mm, 14 parts (5 on the bottom side), 26 nets.

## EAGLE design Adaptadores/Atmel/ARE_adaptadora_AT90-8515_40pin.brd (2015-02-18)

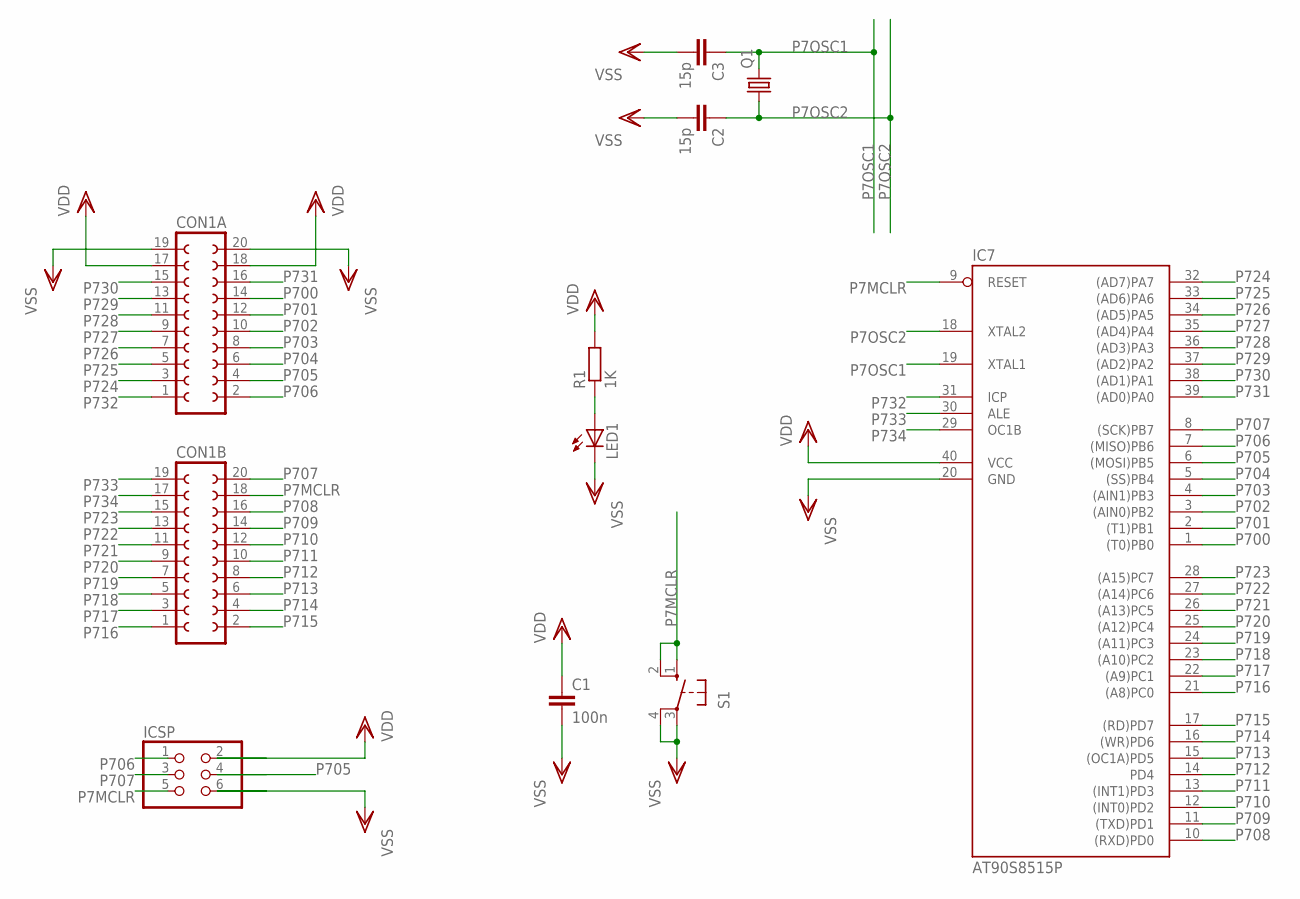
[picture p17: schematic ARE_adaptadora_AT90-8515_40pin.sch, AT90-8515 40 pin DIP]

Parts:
C1: 100n; C0805
C2, C3: 15p; C0805
CON1A, CON1B: FE10-2W
IC7: AT90S8515P; DIL40
ICSP: PINHD-2X3; 2X03
LED1: LED3MM
Q1: CRYSTALHC18U-V; HC18U-V
R1: 1K; R0805
S1: 10-XX; B3F-10XX; MPN B3F-1000

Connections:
unnamed: LED1.A, R1.1
P7MCLR: CON1B.18, IC7.9 (RESET), ICSP.5, S1.1 (S), S1.2 (S1)
P7OSC1: C3.1, IC7.19 (XTAL1), Q1.2
P7OSC2: C2.1, IC7.18 (XTAL2), Q1.1
P700: CON1A.14, IC7.1 ((T0)PB0)
P701: CON1A.12, IC7.2 ((T1)PB1)
P702: CON1A.10, IC7.3 ((AIN0)PB2)
P703: CON1A.8, IC7.4 ((AIN1)PB3)
P704: CON1A.6, IC7.5 ((SS)PB4)
P705: CON1A.4, IC7.6 ((MOSI)PB5), ICSP.4
P706: CON1A.2, IC7.7 ((MISO)PB6), ICSP.1
P707: CON1B.20, IC7.8 ((SCK)PB7), ICSP.3
P708: CON1B.16, IC7.10 ((RXD)PD0)
P709: CON1B.14, IC7.11 ((TXD)PD1)
P710: CON1B.12, IC7.12 ((INT0)PD2)
P711: CON1B.10, IC7.13 ((INT1)PD3)
P712: CON1B.8, IC7.14 (PD4)
P713: CON1B.6, IC7.15 ((OC1A)PD5)
P714: CON1B.4, IC7.16 ((WR)PD6)
P715: CON1B.2, IC7.17 ((RD)PD7)
P716: CON1B.1, IC7.21 ((A8)PC0)
P717: CON1B.3, IC7.22 ((A9)PC1)
P718: CON1B.5, IC7.23 ((A10)PC2)
P719: CON1B.7, IC7.24 ((A11)PC3)
P720: CON1B.9, IC7.25 ((A12)PC4)
P721: CON1B.11, IC7.26 ((A13)PC5)
P722: CON1B.13, IC7.27 ((A14)PC6)
P723: CON1B.15, IC7.28 ((A15)PC7)
P724: CON1A.3, IC7.32 ((AD7)PA7)
P725: CON1A.5, IC7.33 ((AD6)PA6)
P726: CON1A.7, IC7.34 ((AD5)PA5)
P727: CON1A.9, IC7.35 ((AD4)PA4)
P728: CON1A.11, IC7.36 ((AD3)PA3)
P729: CON1A.13, IC7.37 ((AD2)PA2)
P730: CON1A.15, IC7.38 ((AD1)PA1)
P731: CON1A.16, IC7.39 ((AD0)PA0)
P732: CON1A.1, IC7.31 (ICP)
P733: CON1B.19, IC7.30 (ALE)
P734: CON1B.17, IC7.29 (OC1B)
VDD: C1.1, CON1A.17, CON1A.18, IC7.40 (VCC), ICSP.2, R1.2
VSS: C1.2, C2.2, C3.2, CON1A.19, CON1A.20, IC7.20 (GND), ICSP.6, LED1.K (C), S1.3, S1.4 (P1)



Board: 2 copper layers, 55.2 x 37.9 mm, 11 parts (4 on the bottom side), 41 nets.

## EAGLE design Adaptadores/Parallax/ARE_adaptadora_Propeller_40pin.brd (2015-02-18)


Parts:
C49, C52: 100n; C0805
C50, C51: 15p; C0805
IC10: 24LC21AP; DIL8
JP10: M04PTH; 1X04
LED10: LED3MM
Q11: CRYSTALHC18U-V; HC18U-V
R17: 1K; R0805
S10: 10-XX; B3F-10XX; MPN B3F-1000
SV20, SV21: FE10-2W
U$3: P8X32A-D40

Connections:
unnamed: LED10.A, R17.1
P10MCLR: JP10.2, S10.3, S10.4 (P1), U$3.11 (RES/)
P10OSC1: C50.1, Q11.1, U$3.30 (XI)
P10OSC2: C51.1, Q11.2, U$3.31 (XO)
P10RX: JP10.3, SV20.2, U$3.40 (P31)
P10SCL: IC10.6 (SCL), SV20.8, U$3.37 (P28)
P10SDA: IC10.5 (SDA), SV20.6, U$3.38 (P29)
P10TX: JP10.4, SV20.4, U$3.39 (P30)
P1000: SV20.1, U$3.1 (P0)
P1001: SV20.3, U$3.2 (P1)
P1002: SV20.5, U$3.3 (P2)
P1003: SV20.7, U$3.4 (P3)
P1004: SV20.9, U$3.5 (P4)
P1005: SV20.11, U$3.6 (P5)
P1006: SV20.13, U$3.7 (P6)
P1007: SV20.15, U$3.8 (P7)
P1008: SV21.1, U$3.13 (P8)
P1009: SV21.3, U$3.14 (P9)
P1010: SV21.5, U$3.15 (P10)
P1011: SV21.7, U$3.16 (P11)
P1012: SV21.9, U$3.17 (P12)
P1013: SV21.11, U$3.18 (P13)
P1014: SV21.13, U$3.19 (P14)
P1015: SV21.15, U$3.20 (P15)
P1016: SV21.16, U$3.21 (P16)
P1017: SV21.14, U$3.22 (P17)
P1018: SV21.12, U$3.23 (P18)
P1019: SV21.10, U$3.24 (P19)
P1020: SV21.8, U$3.25 (P20)
P1021: SV21.6, U$3.26 (P21)
P1022: SV21.4, U$3.27 (P22)
P1023: SV21.2, U$3.28 (P23)
P1024: SV20.16, U$3.33 (P24)
P1025: SV20.14, U$3.34 (P25)
P1026: SV20.12, U$3.35 (P26)
P1027: SV20.10, U$3.36 (P27)
VDD: C49.1, C52.1, IC10.8 (VCC), R17.2, SV20.19, SV20.20, SV21.17, SV21.18, U$3.12 (VDD), U$3.32 (VDD)
VSS: C49.2, C50.2, C51.2, C52.2, IC10.1 (A0), IC10.2 (A1), IC10.3 (A2), IC10.4 (GND), IC10.7 (VCLK), JP10.1, LED10.K (C), S10.1 (S), S10.2 (S1), SV20.17, SV20.18, SV21.19, SV21.20, U$3.9 (VSS), U$3.10 (BOE/), U$3.29 (VSS)



Board: 2 copper layers, 61.6 x 42.5 mm, 13 parts (5 on the bottom side), 38 nets.

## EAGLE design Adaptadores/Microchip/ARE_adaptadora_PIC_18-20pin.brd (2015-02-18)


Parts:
C72, C76, C77, C78: 18p; C0805
C80, C81: 100n; C0805
IC12: PIC16F628P; DIL18
JP15: M05PTH; 1X05
LED20: LEDCHIPLED_0805; CHIPLED_0805
Q16, Q17: CRYSTALHC18U-V; HC18U-V
R37: 4K7; R0805
R38: 1K; R0805
S13: 10-XX; B3F-10XX; MPN B3F-1000
SV31, SV32: FE10-2W
U$10: PIC16F1829; DIL20

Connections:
unnamed: LED20.A, R38.1
P13GC: IC12.12 (RB6/T1OSO/T1CKI/PGC), JP15.5, SV31.5, SV32.13, U$10.18 (A1/AN1/VREF+/PGC)
P13GD: IC12.13 (RB7/T1OSI/PGD), JP15.4, SV31.7, SV32.15, U$10.19 (A0/AN0/VREF-/DACOUT/PGD)
P13MCLR: IC12.4 (RA5/MCLR/VPP), JP15.1, R37.1, S13.1 (S), SV31.12, SV32.12, U$10.4 (A3/!MCLR)
P1301: IC12.10 (RB4/PGM), SV31.1
P1302: IC12.9 (RB3/CCP1), SV31.2
P1303: IC12.11 (RB5), SV31.3
P1304: IC12.8 (RB2/TX/CK), SV31.4
P1306: IC12.7 (RB1/RX/DT), SV31.6
P1308: IC12.6 (RB0/INT), SV31.8
P1311: C78.1, IC12.15 (RA6/OSC2/CLKOUT), Q17.1, SV31.11
P1313: C72.1, IC12.16 (RA7/OSC1/CLKIN), Q17.2, SV31.13
P1314: IC12.3 (RA4/TOCKI/CMP2), SV31.14
P1315: IC12.17 (RA0/AN0), SV31.15
P1316: IC12.2 (RA3/AN3/CMP1), SV31.16
P1317: IC12.18 (RA1/AN1), SV31.17
P1318: IC12.1 (RA2/AN2/VREF), SV31.18
P1319: SV31.19, U$10.11 (B6/SCL1/SCK1)
P1320: SV31.20, U$10.10 (B7/TX*/SCL2/SCK2)
P1321: SV32.1, U$10.12 (B5/AN11/RX*/SDA2/SDI2)
P1322: SV32.2, U$10.9 (C7/AN9/SDO1)
P1323: SV32.3, U$10.13 (B4/AN10/SDA1/SDI1)
P1324: SV32.4, U$10.8 (C6/AN8/!SS1)
P1325: SV32.5, U$10.14 (C2/AN6)
P1326: SV32.6, U$10.7 (C3/AN7/CCP2*)
P1327: SV32.7, U$10.15 (C1/AN5/SDO2*)
P1328: SV32.8, U$10.6 (C4/TX*)
P1329: SV32.9, U$10.16 (C0/AN4/!SS2!*)
P1330: SV32.10, U$10.5 (C5/CCP1/RX*)
P1331: SV32.11, U$10.17 (A2/AN2/CCP3)
P1334: C77.1, Q16.1, SV32.14, U$10.3 (A4/AN3/OSC2/!SS2!*)
P1336: C76.1, Q16.2, SV32.16, U$10.2 (A5/OSC1/CCP2*/SDO2*)
VCC: C80.1, C81.1, IC12.14 (VDD), JP15.2, R37.2, R38.2, SV31.9, SV31.10, SV32.17, SV32.18, U$10.1 (VDD)
VSS: C72.2, C76.2, C77.2, C78.2, C80.2, C81.2, IC12.5 (VSS), JP15.3, LED20.C, S13.3, SV32.19, SV32.20, U$10.20 (VSS)



Board: 2 copper layers, 58.7 x 25.4 mm, 17 parts (7 on the bottom side), 34 nets.

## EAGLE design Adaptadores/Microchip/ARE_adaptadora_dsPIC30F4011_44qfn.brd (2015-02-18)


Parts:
C20, C21, C22, C37: 100n; C0805
C23, C24: 18p; C0805
JP6: M05PTH; 1X05
LED6: LEDCHIPLED_0805; CHIPLED_0805
Q7: CRYSTALHC18U-V; HC18U-V
R11: 4K7; R0805
R12: 1K; R0805
S6: 10-XX; B3F-10XX; MPN B3F-1000
SV8, SV13: FE10-2W
U$2: DSPIC30F4011; QFN44ML8X8

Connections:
unnamed: LED6.A, R12.1
P6GC: JP6.5, SV8.9, U$2.1 (01.PGC)
P6GD: JP6.4, SV8.10, U$2.44 (44.PGD)
P6MCLR: JP6.1, R11.1, S6.1 (S), SV13.6, U$2.18 (18./MCLR)
P6OSC1: C23.1, Q7.2, SV13.16, U$2.32 (32.OSC1)
P6OSC2: C24.1, Q7.1, SV13.15, U$2.33 (33.OSC2)
P601: SV8.1, U$2.35 (35.RC14)
P602: SV8.2, U$2.34 (34.RC13)
P603: SV8.3, U$2.37 (37.RD1)
P604: SV8.4, U$2.36 (36.RE8)
P605: SV8.5, U$2.41 (41.RD2)
P606: SV8.6, U$2.38 (38.RD3)
P607: SV8.7, U$2.43 (43.RF6)
P608: SV8.8, U$2.42 (42.RD0)
P611: SV8.11, U$2.3 (03.RF4)
P612: SV8.12, U$2.2 (02.RF5)
P613: SV8.13, U$2.5 (05.RF0)
P614: SV8.14, U$2.4 (04.RF1)
P616: SV8.16, U$2.9 (09.RE5)
P617: SV8.17, U$2.10 (10.RE4)
P618: SV8.18, U$2.11 (11.RE3)
P619: SV8.19, U$2.12 (12.RE2)
P620: SV8.20, U$2.13 (13.NC)
P621: SV13.1, U$2.14 (14.RE1)
P622: SV13.2, U$2.15 (15.RE0)
P625: SV13.5, U$2.19 (19.RB0)
P627: SV13.7, U$2.21 (21.RB2)
P628: SV13.8, U$2.20 (20.RB1)
P629: SV13.9, U$2.23 (23.RB4)
P630: SV13.10, U$2.22 (22.RB3)
P631: SV13.11, U$2.25 (25.RB6)
P632: SV13.12, U$2.24 (24.RB5)
P633: SV13.13, U$2.27 (27.RB8)
P634: SV13.14, U$2.26 (26.RB7)
VCC: C20.1, C21.1, C22.1, C37.1, JP6.2, R11.2, R12.2, SV13.17, SV13.18, U$2.7 (07.VDD), U$2.8 (08.VDD), U$2.17 (17.AVDD), U$2.28 (28.VDD), U$2.29 (29.VDD), U$2.40 (40.VDD)
VSS: C20.2, C21.2, C22.2, C23.2, C24.2, C37.2, JP6.3, LED6.C, S6.3, SV8.15, SV13.3, SV13.4, SV13.19, SV13.20, U$2.6 (06.VSS), U$2.16 (16.AVSS), U$2.30 (30.VSS), U$2.31 (31.VSS), U$2.39 (39.VSS), U$2.EXP (45.MET)



Board: 2 copper layers, 53.7 x 27.9 mm, 15 parts (7 on the bottom side), 36 nets.

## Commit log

2013-03-08 Added first batch of pcbs
    Added Base board versión 1.0
    Added first set of adapter boards for Microchip 6, 8, 14, 44 and 64
    pins.
    Added some preliminary set of add-on boards.
    [ARE_adaptadores.brd, ARE_adaptadores.sch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]
2013-03-19 Added first batch of Microchip adapter pcbs
    A 10x10cm board consisting of 4 Microchip adapters:
    * 64 pin micro for PIC32, dsPIC and PIC24.
    * 44 pin micro for PIC32, dsPIC and PIC24.
    * 44 pin micro for PIC16 and PIC18.
    * 8/14 pin micro for PIC10, PIC12 and PIC16.
    Theres also a square ruler mm/inch as a bonnus.
    [ARE_adaptadores_final.brd, ARE_adaptadores_final.sch]
2013-04-15 Adaptadores v1.01
    Added adapter board for this micros:
    * Microchip dsPIC30F4011 in QFN-44 format.
    * Microchip PIC32/dsPIC33 in SOIC-28 format.
    * Atmel AT908515 in DIP-40 format.
    * Atmel AT908535 in DIP-40 format.
    * Microchip PIC16/18 in DIP-40 format.
    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
    [ARE_adaptadores_v101.brd, ARE_adaptadores_v101.sch]
2013-04-16 Added template for pin labels
    Added a template for pin labels in .DXF format. It is still just a
    template and it those not correspond to any final adapter pcb yet. It is
    just to see the idea. I hope to have it finished soon.
    [Plantilla_pins_entrenadora.dxf]
2013-04-26 Added template for pin labels
    Added a template for pin labels. This one is in .XLS format (97-2003
    version) instead of .DXF. I think this is a much more convenient format
    and easier to modify, print and create new ones.
    [Plantilla_pins_entrenadora.xls]
2013-05-07 Added new 64 pin version of base trainer
    * Added a new 64 pin version of base trainer. These are the changes:
    -> Reduced main connector from 3x30 to 2x30. Now it can accept
    microcontroles up to 64 pin, wich is enough for most hobbyst.
    -> Redistributed most components to gain some space. Thanks to this
    increment, now it is possible to place a full breadboard.
    -> Reduced from 8 to only 4 pushbuttons.
    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
    [ARE_entrenadora_modular_doblecara_bis.GBL, ARE_entrenadora_modular_doblecara_bis.GBO, ARE_entrenadora_modular_doblecara_bis.GBP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]
2015-02-18 New version and a massive re-arrengement
    New version of base trainer. Now it is called Ardu-Trainer MultiMicro,
    as it has an ATMEGA32U4 with all its pins available. It can be
    programmed with Arduino bootloader or directly with your own firmware.
    All of MultiMicro adapters have been revised, cleaned and sorted.
    [ARE_adaptadora_AT90-8515_40pin.brd, ARE_adaptadora_AT90-8515_40pin.sch, ARE_adaptadora_AT90-8535_40pin.brd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]
2015-02-18 Added STM32 adapter
    Added an STM32F4xx adapter 64 pin version.
    Also added a couple of files missing from OLD adapters.
    [ARE_adaptadora_STM32_64pin.brd, ARE_adaptadora_STM32_64pin.sch, avr3.brd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]

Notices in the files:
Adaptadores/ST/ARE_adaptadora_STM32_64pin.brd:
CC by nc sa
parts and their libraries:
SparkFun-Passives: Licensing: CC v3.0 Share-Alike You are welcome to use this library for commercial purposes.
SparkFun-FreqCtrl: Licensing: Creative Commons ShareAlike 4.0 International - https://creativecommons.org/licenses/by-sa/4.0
